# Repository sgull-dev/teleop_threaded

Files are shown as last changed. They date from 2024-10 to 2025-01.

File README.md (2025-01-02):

# Tele-Operated Robotics Platform
This repo outlines the documentation for a tele-operated threaded mini-tank robot system. The robot is controlled with a radio-controller, that sends it's signals to the tank. This will interpret the signals and run it's two DC motors with required PWM signals.
This repo documents the implementation of a treaded robot platform controlled with a RC link. The system interprets RC inputs to generate appropiate PWM signals for it's two DC motors, enabling tank-style steering and locomotion.

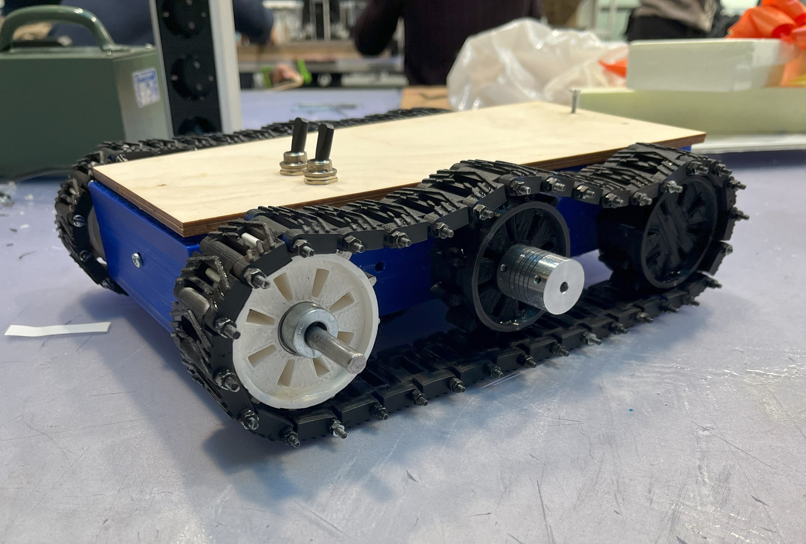
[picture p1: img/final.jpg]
Final

## Electronics
Parts List:
- Arduino
- L298N Dual-Motor Driver
- 12V DC Motors
- 3S Lipo
- Joysticks
- nRF24L01 transceivers

The wiring diagrams showcase both the robot and controller side. On the controller inputs from two joysticks are read and sent over on the nRF24L01 radio transceivers. The same module will receive it on the robot and respond accordingly.
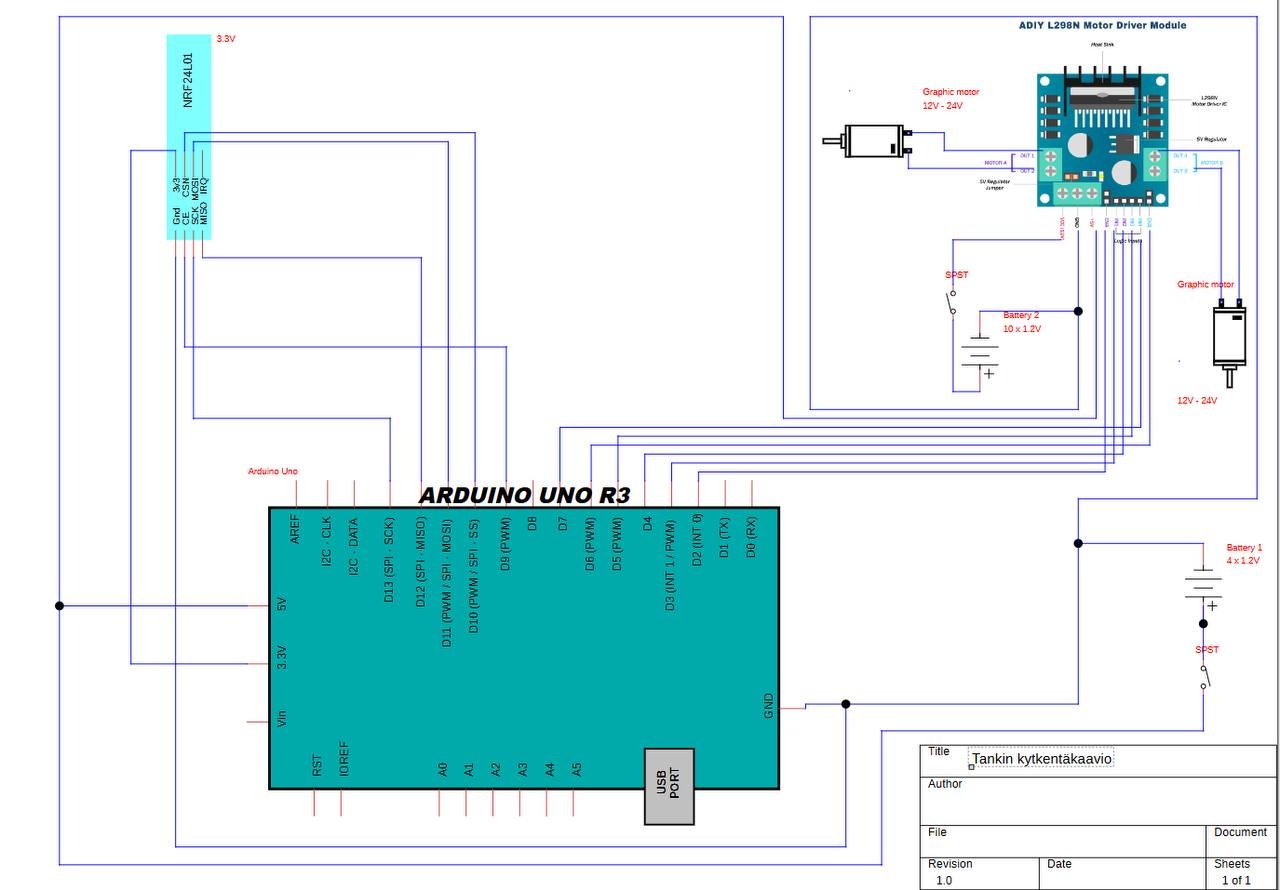
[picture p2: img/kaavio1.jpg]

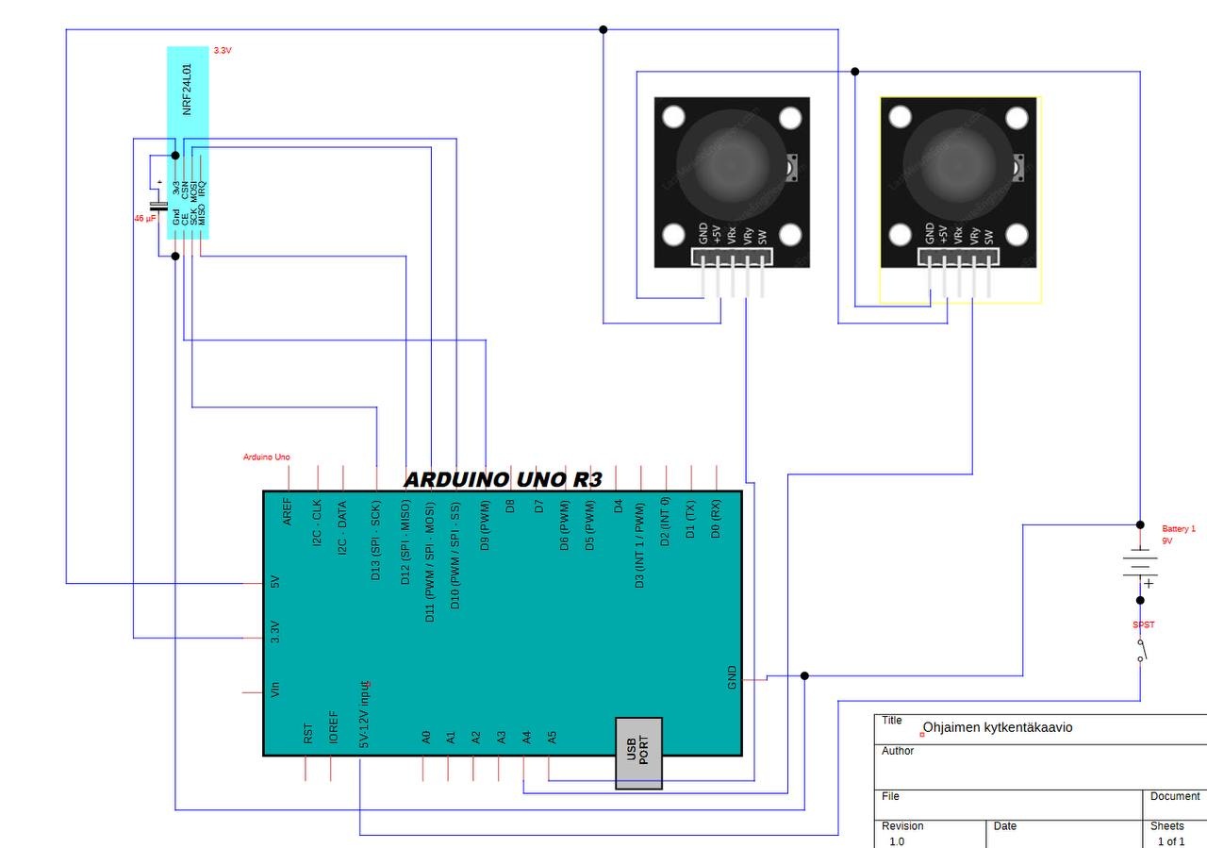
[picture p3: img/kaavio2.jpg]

## Code
The tank's receiver code has 3 functions per motor to either go forward, back or stop. A additional PWM signal is also sent to the motor driver to control the speed of movement. A robust connection reboot system has been developed; the robot will automatically reconnect the RC Link in case it notices a disconnection. This happens within a couple hundred ms and is not noticeable by the user as it does not immediately stop the current instruction set.
The controller's code is very simple, just sending over the analog data from the joystick's potentiometers in a value range of [0, 1023].
## CAD
The frame of the tank is CAD Designed and 3D-printed. The motors have their own mounts to secure them tightly to the frame. The shaft of the motors is brought as down as possible to give us maximal ground clearance. 

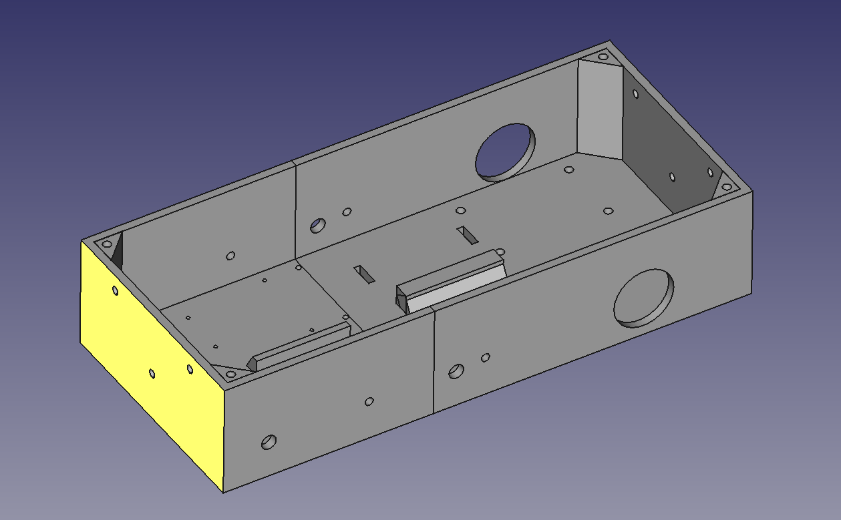
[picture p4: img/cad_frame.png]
cad_frame

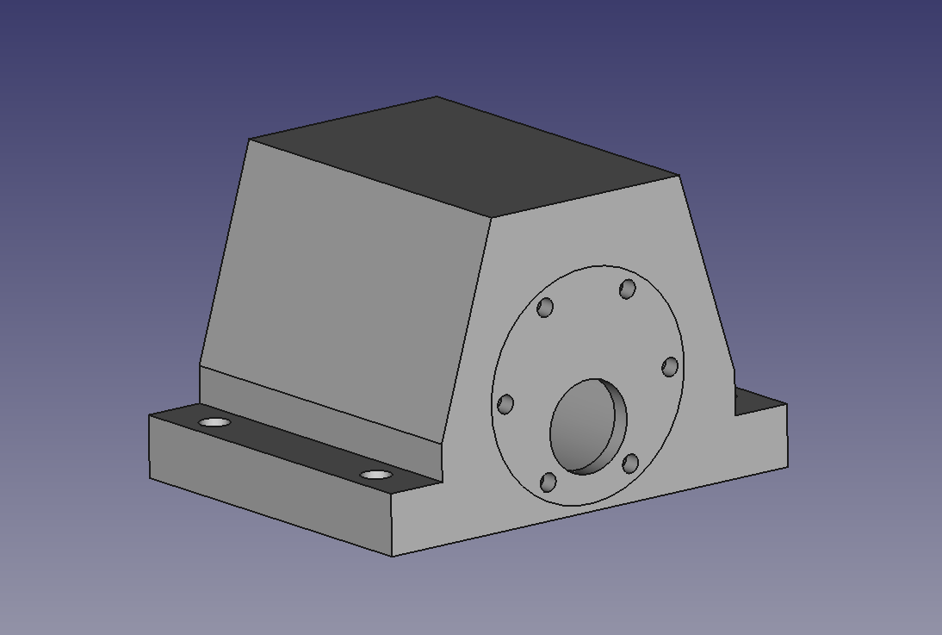
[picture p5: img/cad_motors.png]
CAD Motors

We also included a CAD design for the radio controller with two joysticks.

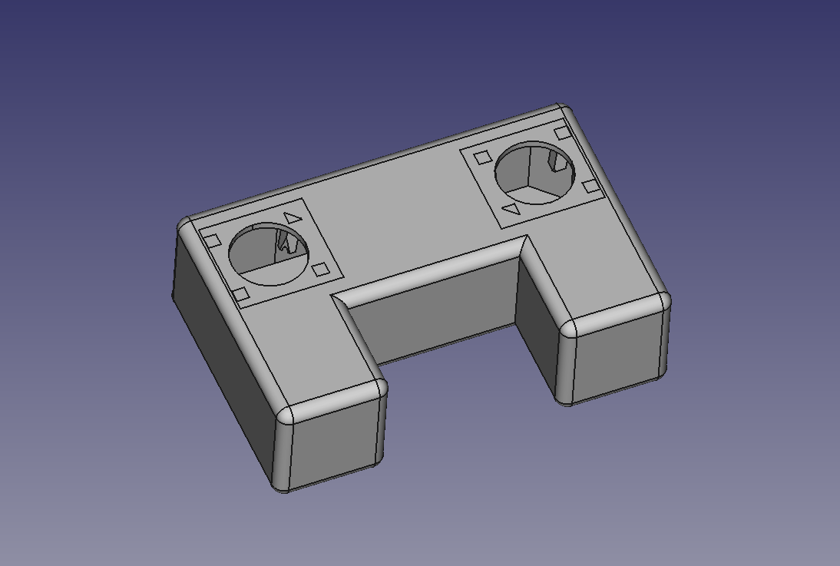
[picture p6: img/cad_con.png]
Controller

## Field Testing
The Robot was tested outside in rougher terrain, plowing through snow. The motors do offer enough torque to keep it moving, but more would be preferred. There is an issue with snow packing up on the threads making it harder to spin and enabling them to fall off. This likely wouldn't be an issue without snow. 
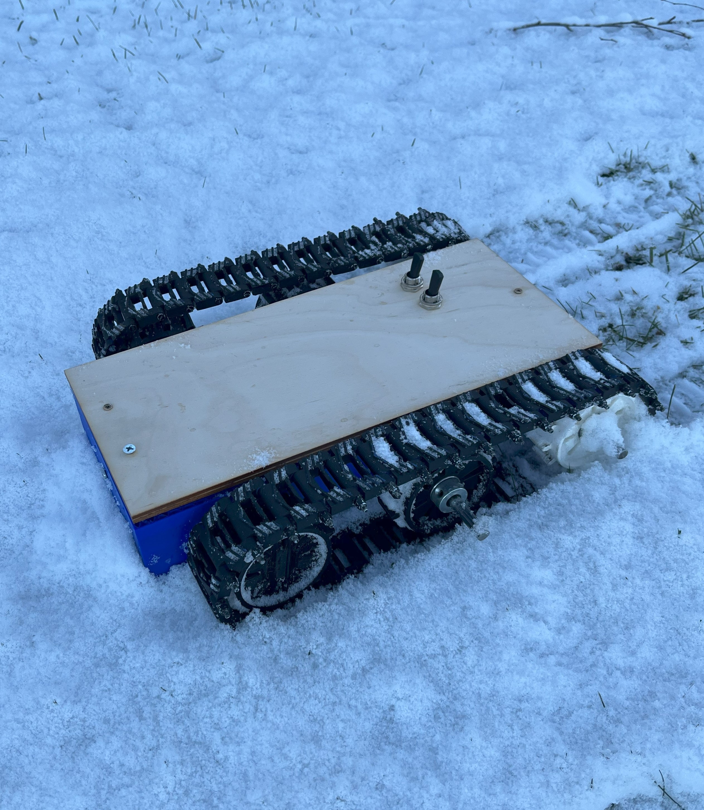
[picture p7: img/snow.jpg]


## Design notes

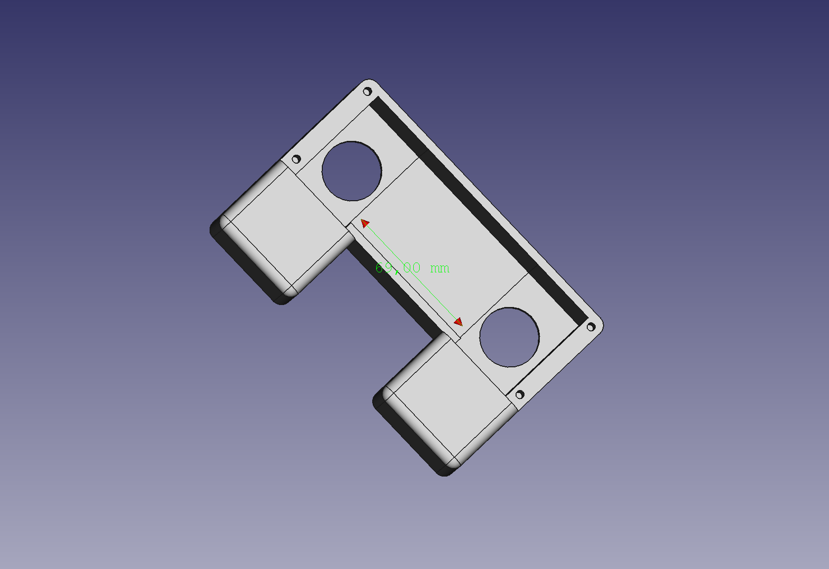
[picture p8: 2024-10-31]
img/controllerframe.PNG

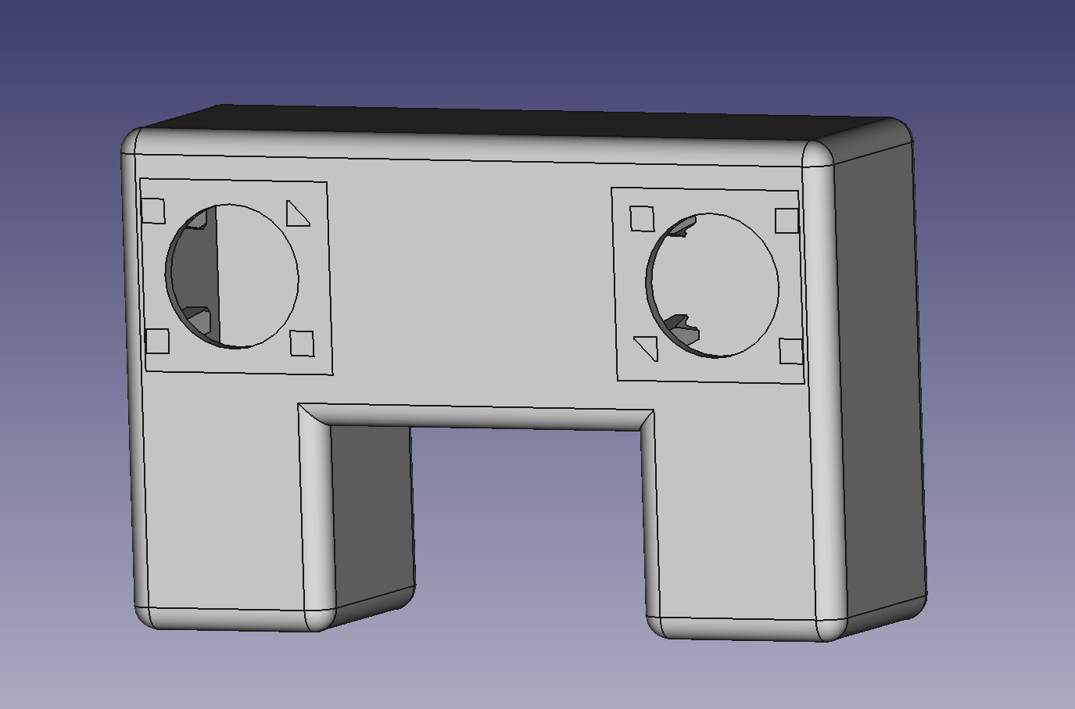
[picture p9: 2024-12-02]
img/controller_cad_2.PNG

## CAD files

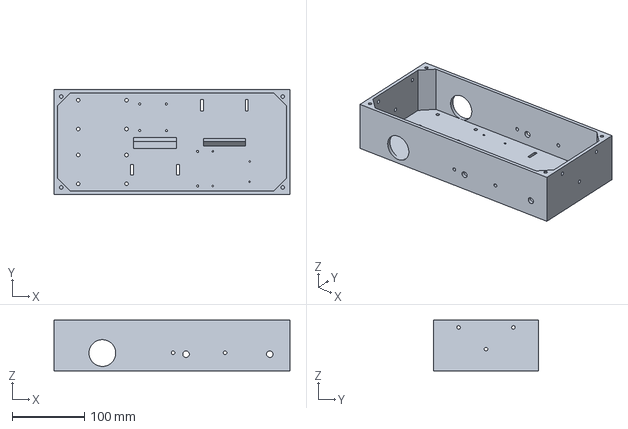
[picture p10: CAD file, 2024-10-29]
cad/frame_full_V5.3mf
327.0 x 146.0 x 70.0 mm

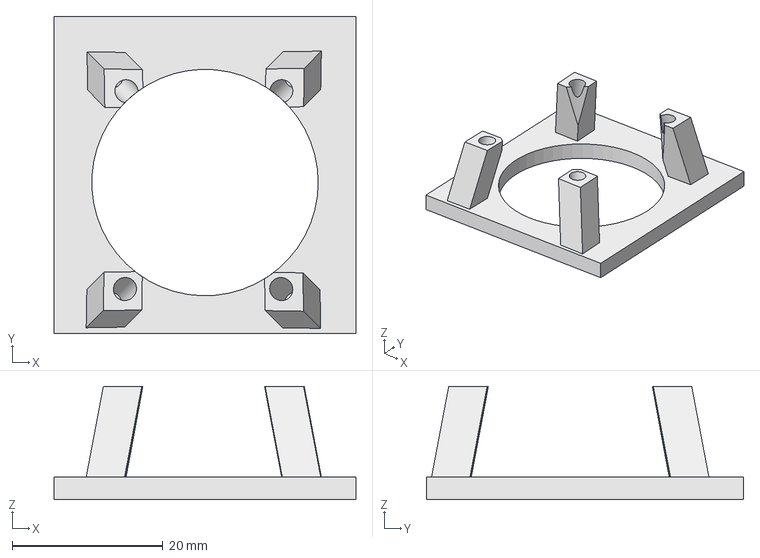
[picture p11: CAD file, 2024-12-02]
cad/Controller_Top_Test.FCStd
40.0 x 42.0 x 15.0 mm

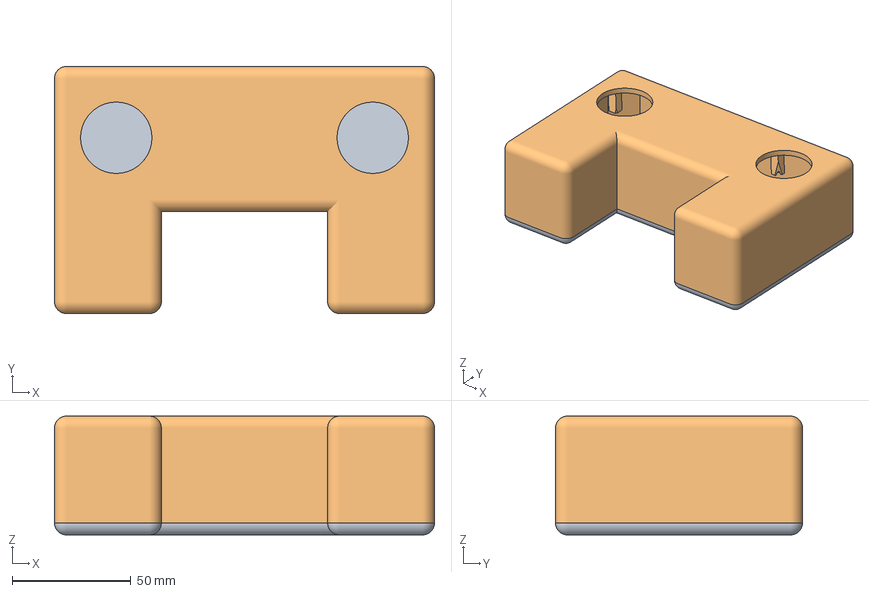
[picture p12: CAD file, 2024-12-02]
cad/Controller_2.3mf
160.0 x 104.0 x 50.0 mm

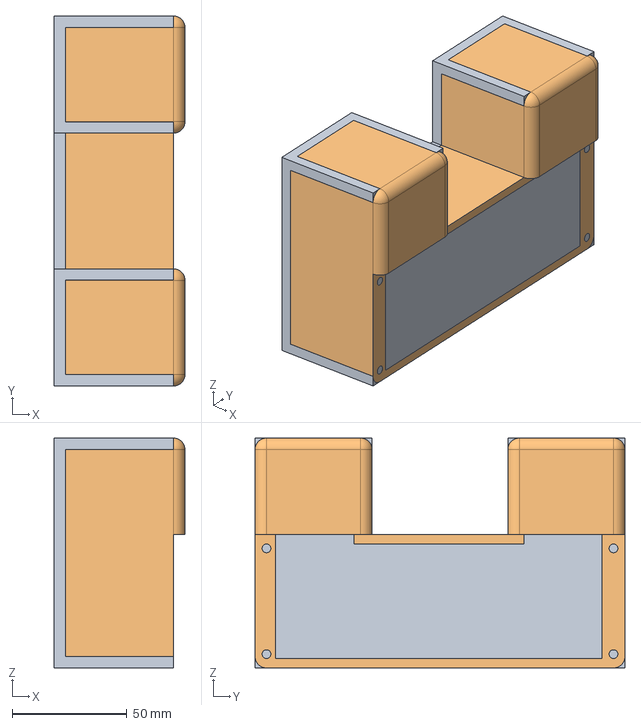
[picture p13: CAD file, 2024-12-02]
cad/controller.FCStd
57.0 x 161.0 x 100.0 mm

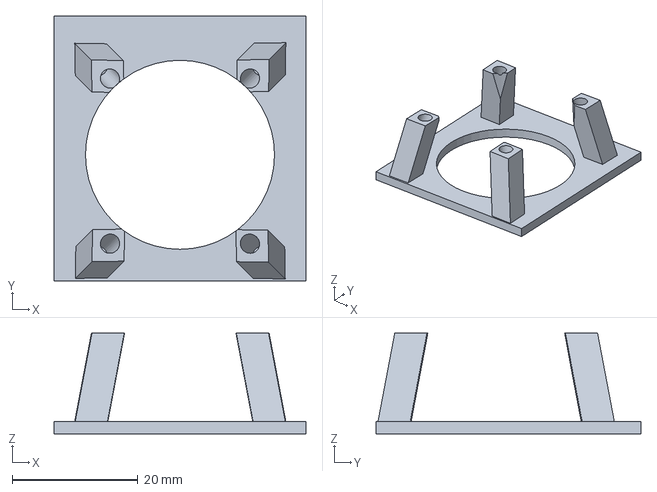
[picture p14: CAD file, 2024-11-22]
cad/controller_test.3mf
40.0 x 42.0 x 16.0 mm

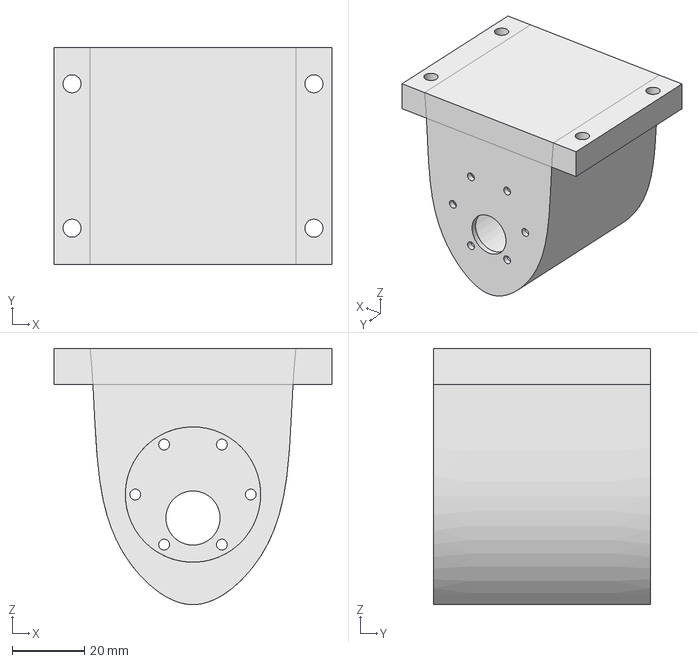
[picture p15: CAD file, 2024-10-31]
cad/Motor_Support.FCStd
77.0 x 60.0 x 71.0 mm

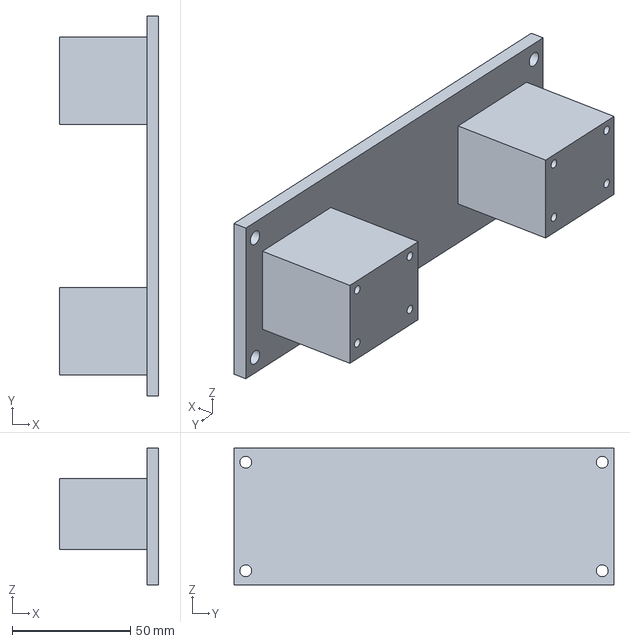
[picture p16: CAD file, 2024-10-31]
cad/controllerbackplate.3mf
42.0 x 161.0 x 58.0 mm

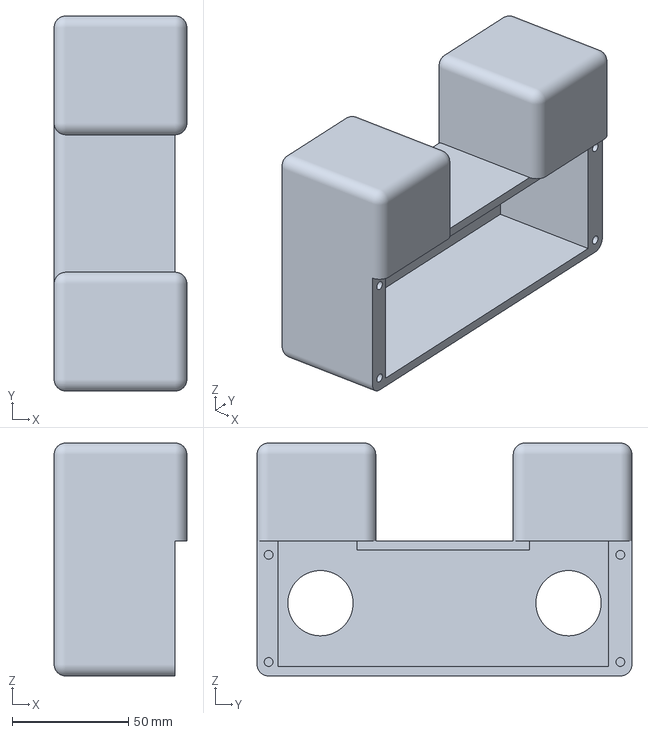
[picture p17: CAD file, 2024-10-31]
cad/controllerframe.3mf
57.0 x 161.0 x 100.0 mm

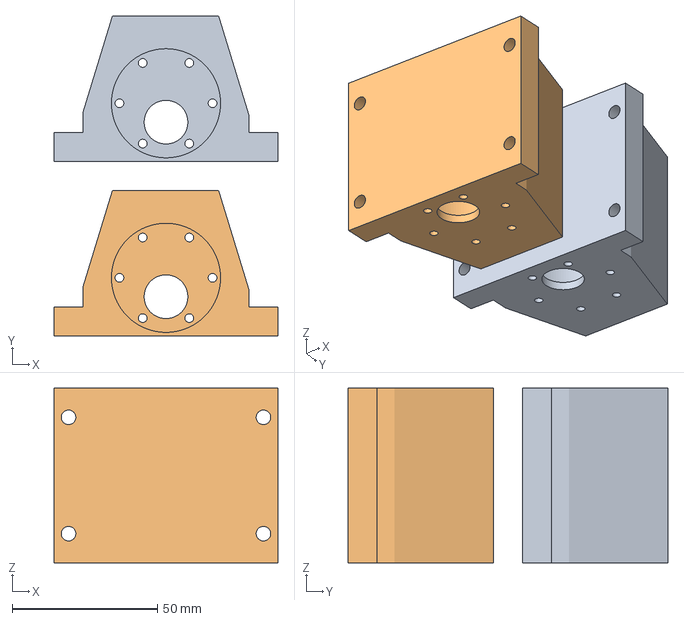
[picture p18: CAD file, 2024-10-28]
cad/Motor_Support_Print_Project.3mf
77.0 x 110.0 x 60.0 mm
motorsupport2-Fusion.3mf
motorsupport2-Fusion.3mf(1)

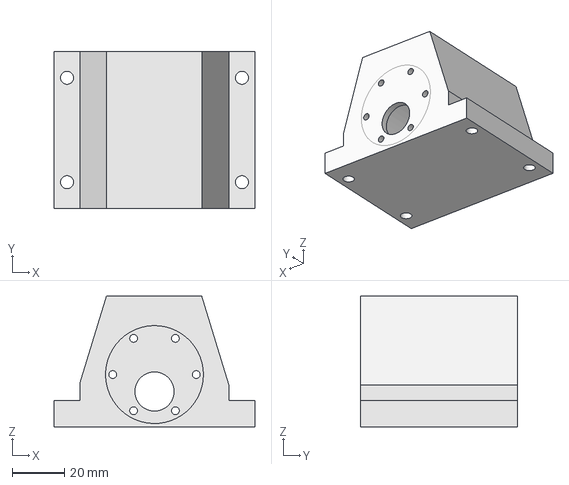
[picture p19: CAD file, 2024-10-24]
cad/tankv2.FCStd
77.0 x 60.0 x 50.0 mm

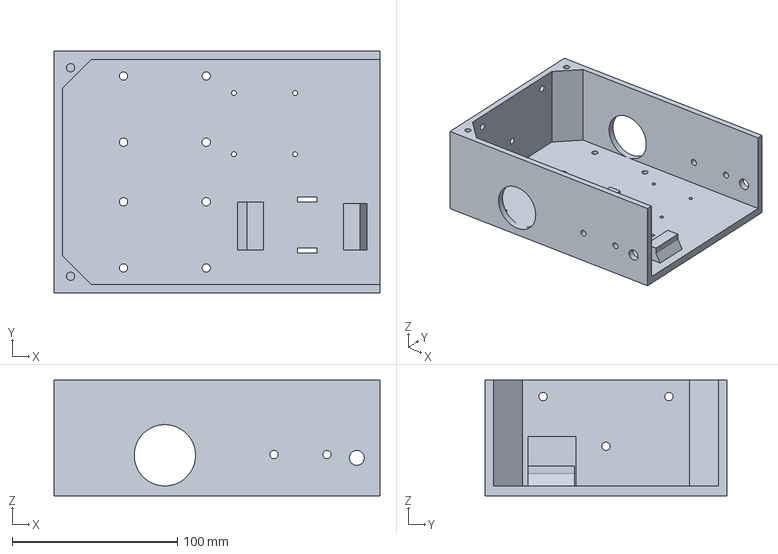
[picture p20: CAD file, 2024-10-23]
cad/frame_part_1.3mf
197.0 x 146.0 x 70.0 mm

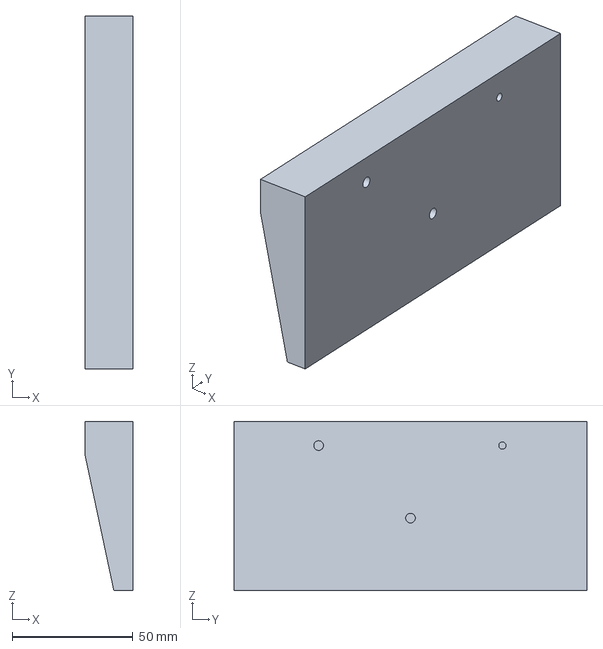
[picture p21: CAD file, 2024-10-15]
cad/back.3mf
20.0 x 146.0 x 70.0 mm

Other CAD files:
cad/Controller_Version2.FCStd
cad/Controller_Top_Test-2.3mf
cad/tank_frame.FCStd
cad/motorsupport2-Fusion.3mf
cad/frame_2.3mf
cad/frame_full_V4.3mf
cad/frame_full_V3.3mf

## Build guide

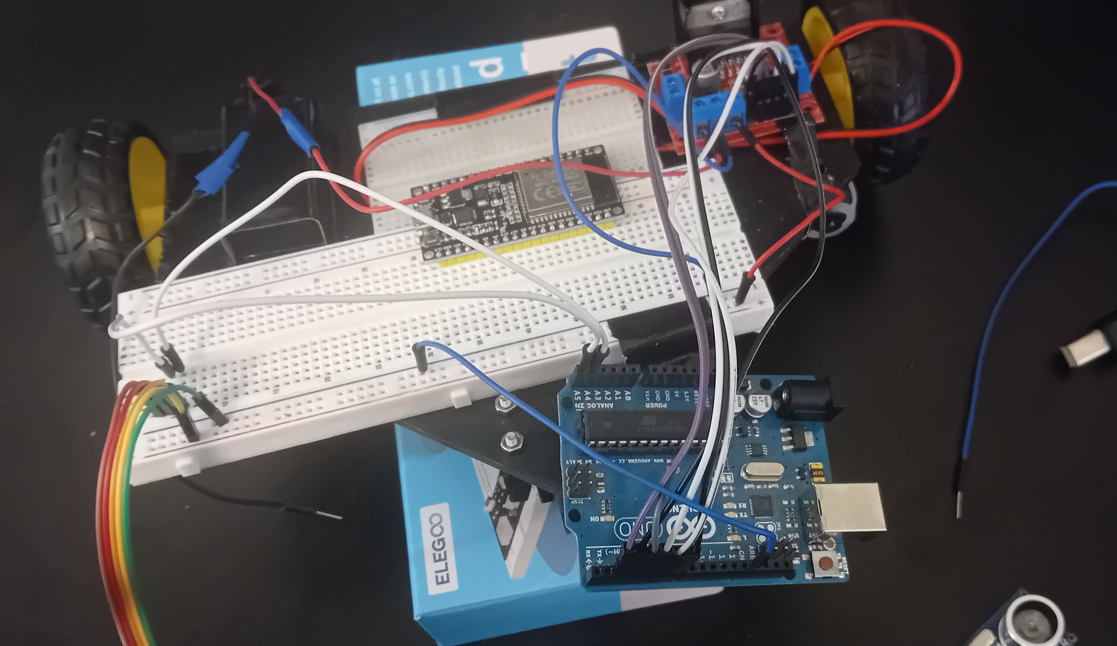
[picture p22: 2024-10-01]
img/joystick_l298n_example_wiring.jpg

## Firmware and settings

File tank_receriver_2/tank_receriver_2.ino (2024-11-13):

#include "Arduino.h"
#include "SPI.h" 
#include "RF24.h" 
#include "nRF24L01.h" 
#define DEAD_ZONE 15
#define CE_PIN 9 
#define CSN_PIN 10 
#define INTERVAL_MS_SIGNAL_LOST 300
#define INTERVAL_MS_SIGNAL_RETRY 125

RF24 radio(CE_PIN, CSN_PIN); 
const byte address[6] = "10101"; 
//NRF24L01 buffer limit is 32 bytes (max struct size) 
struct payload { 
   int data1; 
   int data2; 
}; 
payload payload; 
unsigned long lastSignalMillis = 0; 


// L298N Motor Controller Pins
const int left1 = 2;
const int left2 = 4;
const int leftPWM = 3;
const int right1 = 5;
const int right2 = 7;
const int rightPWM = 6;

// Data
int x1 = 0;
int x2 = 0;
void setup() {
    Serial.begin(115200); 
    setupRadio();
    
    // Set all the motor control pins to outputs
    pinMode(leftPWM, OUTPUT);
    pinMode(rightPWM, OUTPUT);
    pinMode(left1, OUTPUT);
    pinMode(left2, OUTPUT);
    pinMode(right1, OUTPUT);
    pinMode(right2, OUTPUT);
    
    // Turn off motors - Initial state
    digitalWrite(left1, LOW);
    digitalWrite(left2, LOW);
    digitalWrite(right1, LOW);
    digitalWrite(right2, LOW);
}

void setupRadio() {
    radio.begin(); 
    radio.setAutoAck(false);
    radio.setDataRate(RF24_250KBPS);
    radio.setPALevel(RF24_PA_MIN);
    radio.setPayloadSize(sizeof(payload)); 
    radio.openReadingPipe(0, address); 
    radio.startListening(); 
}


void loop () {
  
   unsigned long currentMillis = millis(); 
   if (radio.available() > 0) { 
     radio.read(&payload, sizeof(payload)); 
     Serial.println("Received"); 
     Serial.print("Controller 1:"); 
     Serial.println(payload.data1);
     Serial.print("Controller 2:"); 
     Serial.println(payload.data2);
     lastSignalMillis = currentMillis;
     x1 = payload.data1;
     x2 = payload.data2;

    // Left Motor Control
    if (x1 < 511 - DEAD_ZONE) {
      left_back();
      int speed = (511-x1)/2;
      analogWrite(leftPWM, speed);
    } else if (x1 > 511 + DEAD_ZONE) {
      left_forward();
      int speed = (x1-512)/2;
      analogWrite(leftPWM, speed);
    } else {
      left_stop();
    }

    // Right motor control 
    if (x2 < 511 - DEAD_ZONE) {
        right_back();
        int speed = (511 - x2) / 2;
        analogWrite(rightPWM, speed);
    } else if (x2 > 511 + DEAD_ZONE) {
        right_forward();
        int speed = (x2 - 512) / 2;
        analogWrite(rightPWM, speed);
    } else {
        right_stop();
    }
    delay(30); 
   } 
   if (currentMillis - lastSignalMillis > INTERVAL_MS_SIGNAL_LOST) { 
     //Swapped these back this way; It's better if we stop the motors only after a attempt at reconnection
     // If we instantly get a reconnection then we see no noticeable disconnect
     // Otherwise If we instantly stop it on disconnect, we'll always see a slight pause on disconnect
     lostConnection();
     left_stop();
     right_stop();
   }
}

void lostConnection() 
{ 
   Serial.println("We have lost connection, preventing unwanted behavior");
   reattemptConnection();
   delay(INTERVAL_MS_SIGNAL_RETRY);
} 

void reattemptConnection() {
  //TODO: Could it be possible to do this without Power Cycling? Could be faster.

  Serial.println("Connection lost. Attempting to reconnect...");
  // Power cycle the radio
  radio.powerDown();
  delay(50);
  radio.powerUp();
  
  // Re-initialize the radio
  setupRadio();
  
  Serial.println("Radio reinitialized. Listening for signals...");
}


// Functions for controlling motor directions
void left_forward() {
    digitalWrite(left1, HIGH);
    digitalWrite(left2, LOW);
}

void left_back() {
    digitalWrite(left1, LOW);
    digitalWrite(left2, HIGH);

}

void left_stop() {
    digitalWrite(left1, LOW);
    digitalWrite(left2, LOW);
}

void right_forward() {
    digitalWrite(right1, HIGH);
    digitalWrite(right2, LOW);
}

void right_back() {
    digitalWrite(right1, LOW);
    digitalWrite(right2, HIGH);
}

void right_stop() {
    digitalWrite(right1, LOW);
    digitalWrite(right2, LOW);
}

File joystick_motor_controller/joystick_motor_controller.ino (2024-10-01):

#include "Arduino.h"
#define DEAD_ZONE 15

// Joystick Pins
// TODO: Remove and replace by Radio/BT Input signal
const int joystickX = A4;
const int joystickY = A5;

// L298N Motor Controller Pins
const int left1 = 2;
const int left2 = 4;
const int leftPWM = 3;

const int right1 = 5;
const int right2 = 7;
const int rightPWM = 6;

// Data
int x = 0;
int y = 0;

void setup() {
    // Set all the motor control pins to outputs
    pinMode(leftPWM, OUTPUT);
    pinMode(rightPWM, OUTPUT);
    pinMode(left1, OUTPUT);
    pinMode(left2, OUTPUT);
    pinMode(right1, OUTPUT);
    pinMode(right2, OUTPUT);
    
    // Turn off motors - Initial state
    digitalWrite(left1, LOW);
    digitalWrite(left2, LOW);
    digitalWrite(right1, LOW);
    digitalWrite(right2, LOW);

    //Debugging
    //Serial.begin(9600);
}

void loop () {
    // Joystick value in int [0, 1023]
    x = analogRead(joystickX);
    y = analogRead(joystickY);

    // If Input is less than 511-DEAD_ZONE, it should move back
    // Else if Input is more than 511 + DEAD_ZONE, it should move forward
    // Else stationary
    // If moving, convert the 512-range value into PWM signal for motor speed control

    // Left Motor Control
    if (x < 511 - DEAD_ZONE) {
	left_back();
	int speed = (511-x)/2;
	analogWrite(leftPWM, speed);
    } else if (x > 511 + DEAD_ZONE) {
	left_forward();
	int speed = (x-512)/2;
	analogWrite(leftPWM, speed);
    } else {
	left_stop();
    }

    // Right motor control 
    if (y < 511 - DEAD_ZONE) {
        right_back();
        int speed = (511 - y) / 2;
        analogWrite(rightPWM, speed);
    } else if (y > 511 + DEAD_ZONE) {
        right_forward();
        int speed = (y - 512) / 2;
        analogWrite(rightPWM, speed);
    } else {
        right_stop();
    }

    /*
    Serial.print("Joystick X: ");
    Serial.println(x);
    Serial.print("Joystick Y: ");
    Serial.println(y);
    */
    
    delay(100);  
}

// Functions for controlling motor directions
void left_forward() {
    digitalWrite(left1, HIGH);
    digitalWrite(left2, LOW);
}

void left_back() {
    digitalWrite(left1, LOW);
    digitalWrite(left2, HIGH);

}

void left_stop() {
    digitalWrite(left1, LOW);
    digitalWrite(left2, LOW);
}

void right_forward() {
    digitalWrite(right1, HIGH);
    digitalWrite(right2, LOW);
}

void right_back() {
    digitalWrite(right1, LOW);
    digitalWrite(right2, HIGH);
}

void right_stop() {
    digitalWrite(right1, LOW);
    digitalWrite(right2, LOW);
}

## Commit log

2024-10-01 Code Joystick Usage+Motor Controls based on joystick x/y.
2024-10-15 Cad for frame
    [back.3mf, frame_2.3mf, tank_frame.FCStd]
2024-10-21 Swap lost connection stopping motors to after reconnect attempt
    [tank_receiver.ino]
2024-10-23 Add Support CAD
    [Motor_Support.FCStd]
2024-10-28 Fix Frame Holes/12V Support
    [Motor_Support_Print_Project.3mf, frame_full_V4.3mf, tank_frame.FCStd]
2024-10-29 Some holes
    [frame_full_V5.3mf, tank_frame.FCStd]
2024-11-22 Controller Top Test
    [Controller_Top_Test.FCStd, controller.FCStd, controller_test.3mf]
2024-12-02 Controller 2
    [Controller_2.3mf, Controller_Top_Test-2.3mf, Controller_Top_Test.FCStd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]
